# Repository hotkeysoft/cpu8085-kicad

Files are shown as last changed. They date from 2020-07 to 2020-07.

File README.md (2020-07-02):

# 8085 Computer
Rev A September 2018

Based on original 2001 design

Features
============
- 32KB ROM 
  - Address [0x0000-7FFF]
- 32KB RAM
  - Address [0x8000-FFFF]
- 82C54 PIT (Programmable Interval Timer) 
  - Port [0x40-0x43]
- UART 8250 or 16550 
  - Port [0x60-0x67]
  - Connected to FTDI Serial<->USB Adapter

Notes
============
- No voltage regulation on board, no protection of any kind
- I made a somewhat working BASIC interpreter from scratch that runs on this hardware: [pfe_8085basic](https://github.com/hotkeysoft/pfe_8085basic)

Changes from original design
============
- Changed crystal to 4MHz (CPU Freq = 2MHz)
	- Original design ran at 1.8432MHz (CPU Freq = 921.6KHz)

- Replaced MAX232 chip with FTDI USB module

- Replaced 2 PLA (address latch) with one 74HCT573 (for A[0..7] only, not needed for A[8..15])

- Instead of MISC (0x80) port and additional logic for gating the sound, used /OUT1 of 8250 UART
	- /OUT2 remains unused
	- Needed to invert /OUT2 signal to gate 82C54 timer, and to invert the sound output
		- 2 inverters added to DTGLUE3 (see below)

- Removed IO Decoding chip, moved /UART and /PIT decoding to DTGLUE3
	- Removed IO Decoding for keyboard and LCD

- Glue logic PLA (DTGLUE3) improvements from original DTGLUE1 (see PLD/DTGLUE3.PDS)
	- Removed /IOR, /IOW, /MR, /MW - not needed with properly constructed /CS signals and CPU /WR /RD
		- Added IO Decoding (/CS signal for /UART and /PIT)
	- Removed ALE, no need for inverted signal since switching to 74HCT573
	- Replaced A15 A7 A6 A5 (redundant because A15 == A7 for IO) with A15 A14 A13
		- On 8085, for IO Ports, port address is on both A[0..7] AND A[8..15]
	- 3 inputs and 3 outputs remain on PLA, for future use	

Images
============
PCB Render                                       |  Real PCB
:-----------------------------------------------:|:--------------------------------------------:
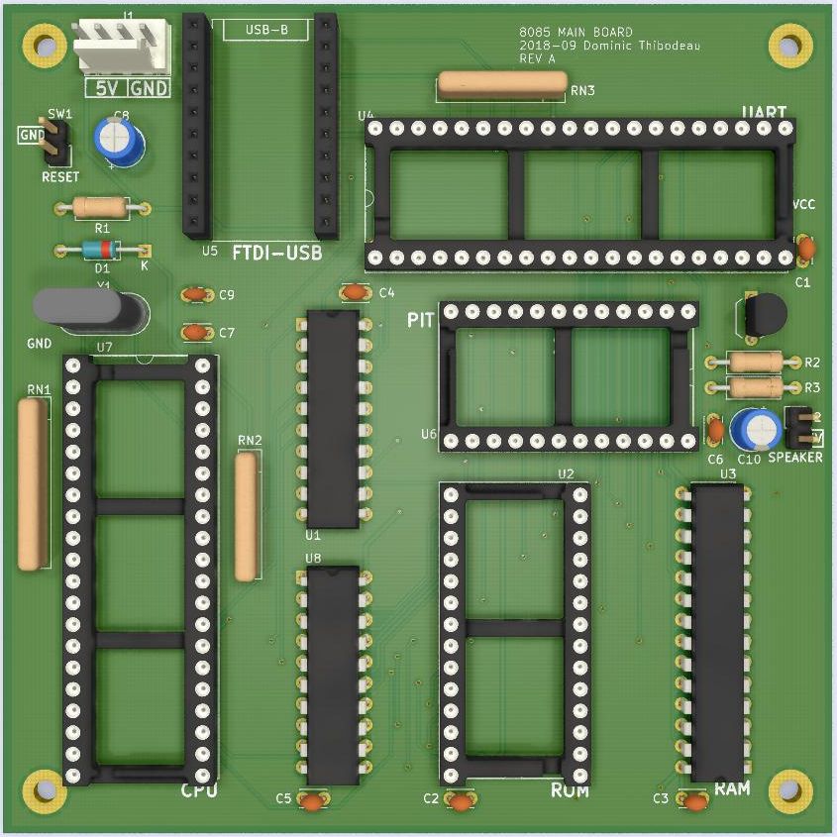
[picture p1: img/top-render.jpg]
PCB Render
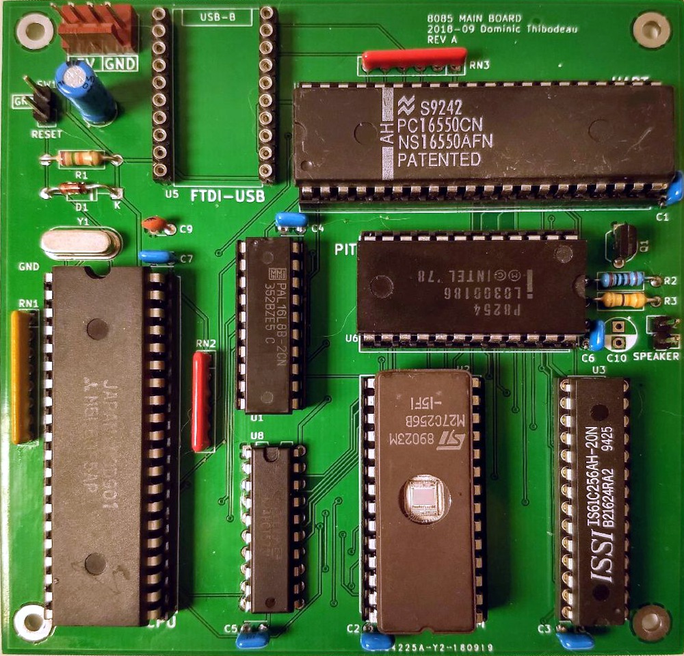
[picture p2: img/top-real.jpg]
Real PCB
 | 

### Schematics (pdf)
- [Complete schematics](./img/schema.pdf)

### PCB Images (svg)
- [Top](./img/pcb-front.svg)
- [Bottom](./img/pcb-back.svg)

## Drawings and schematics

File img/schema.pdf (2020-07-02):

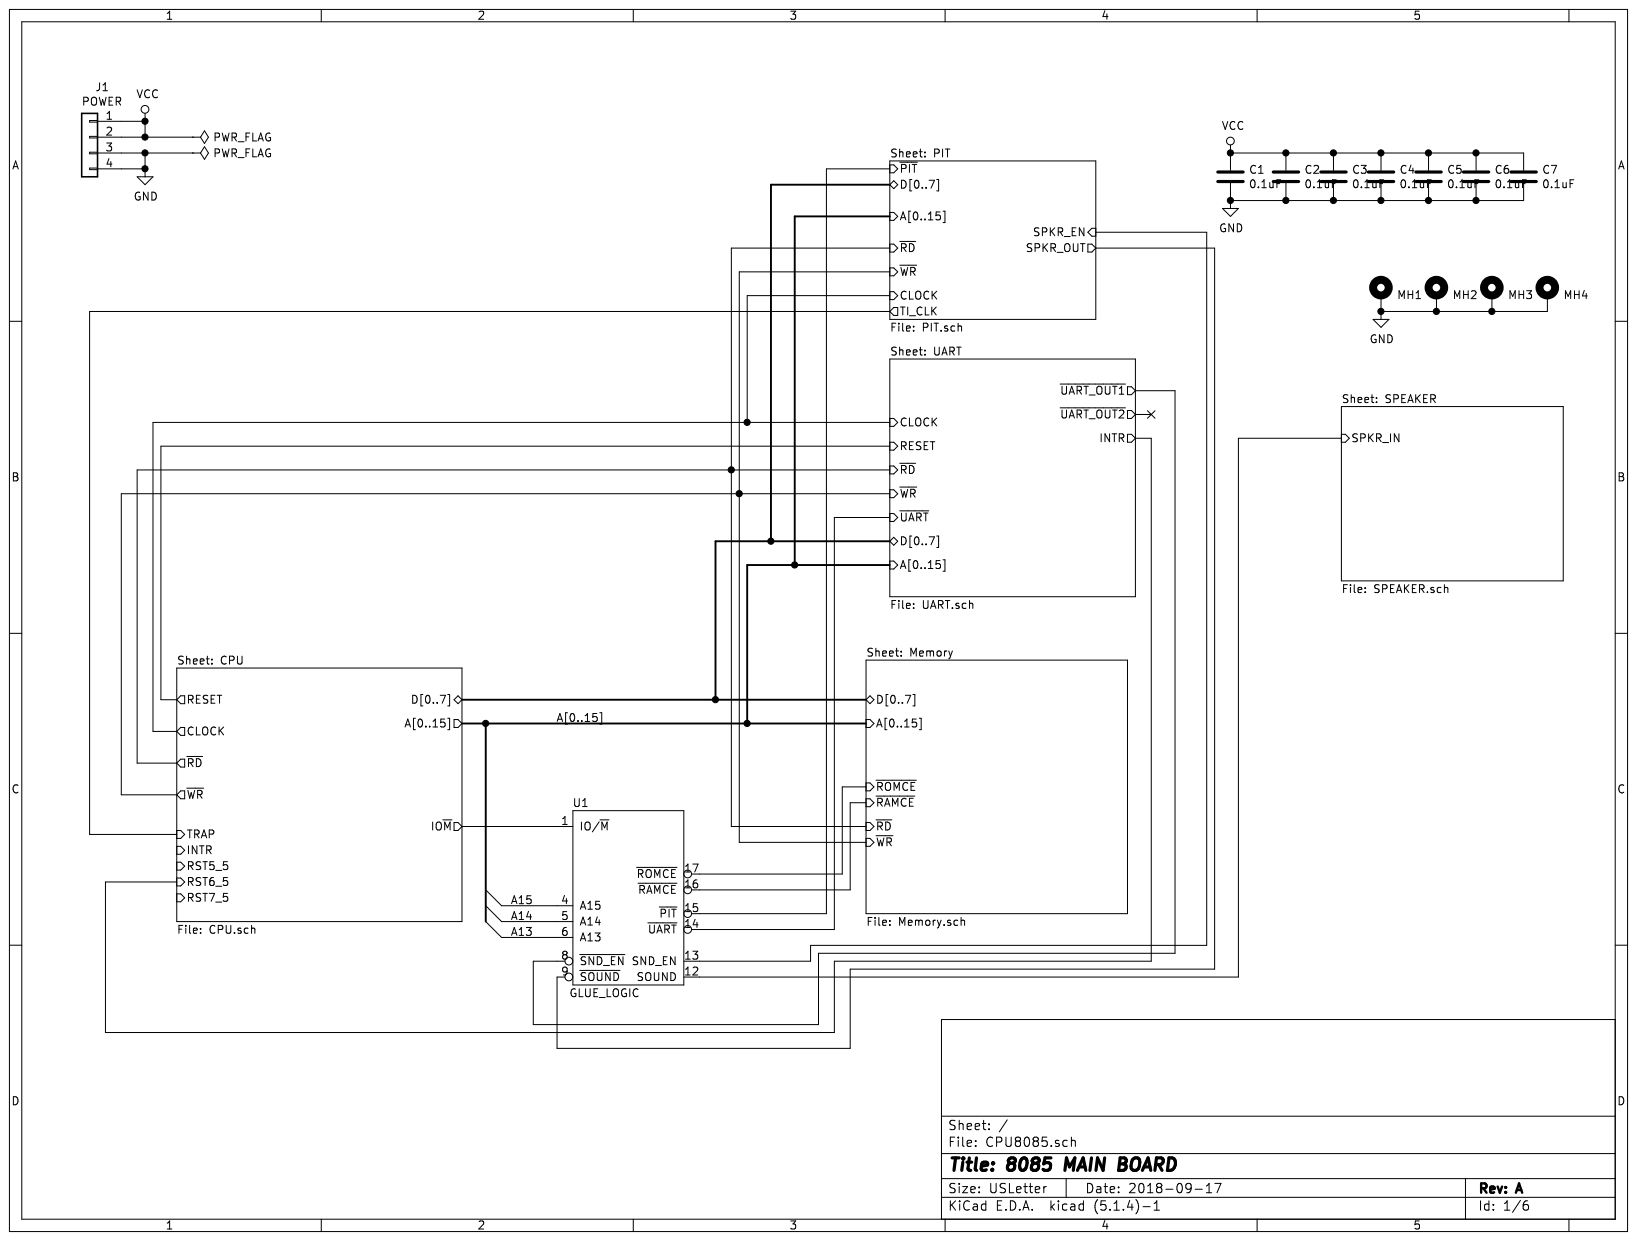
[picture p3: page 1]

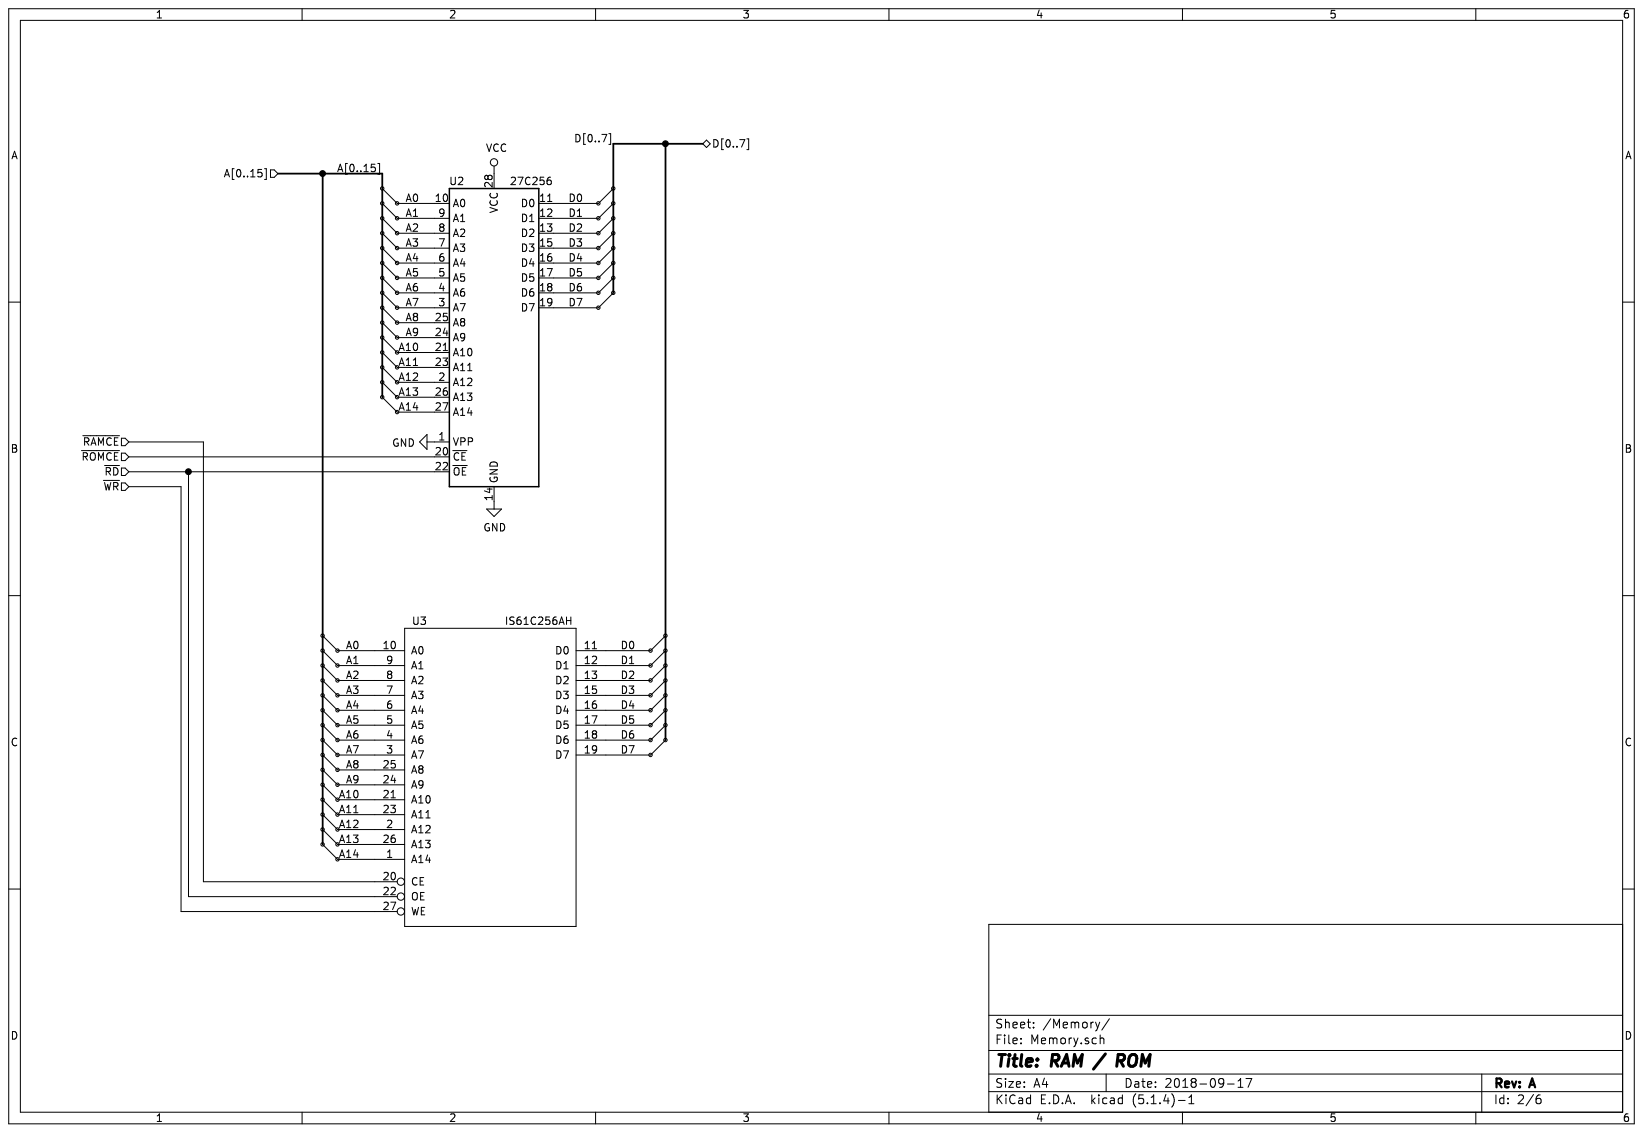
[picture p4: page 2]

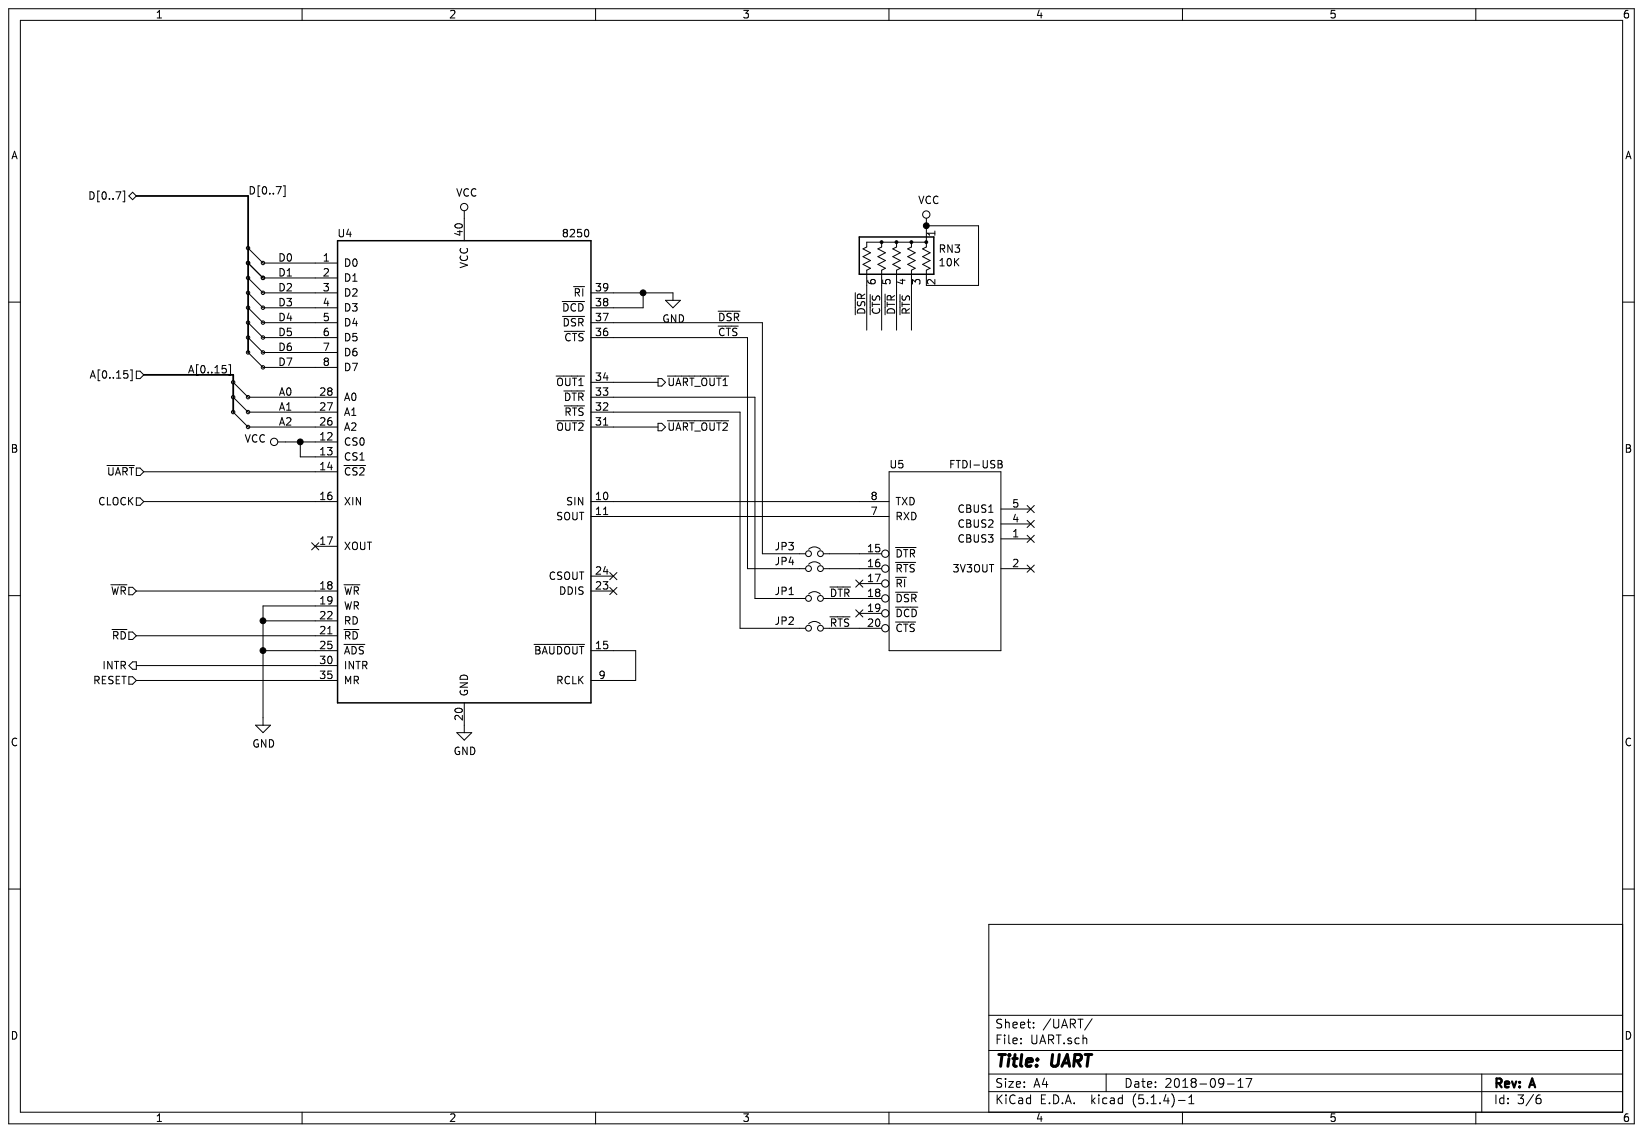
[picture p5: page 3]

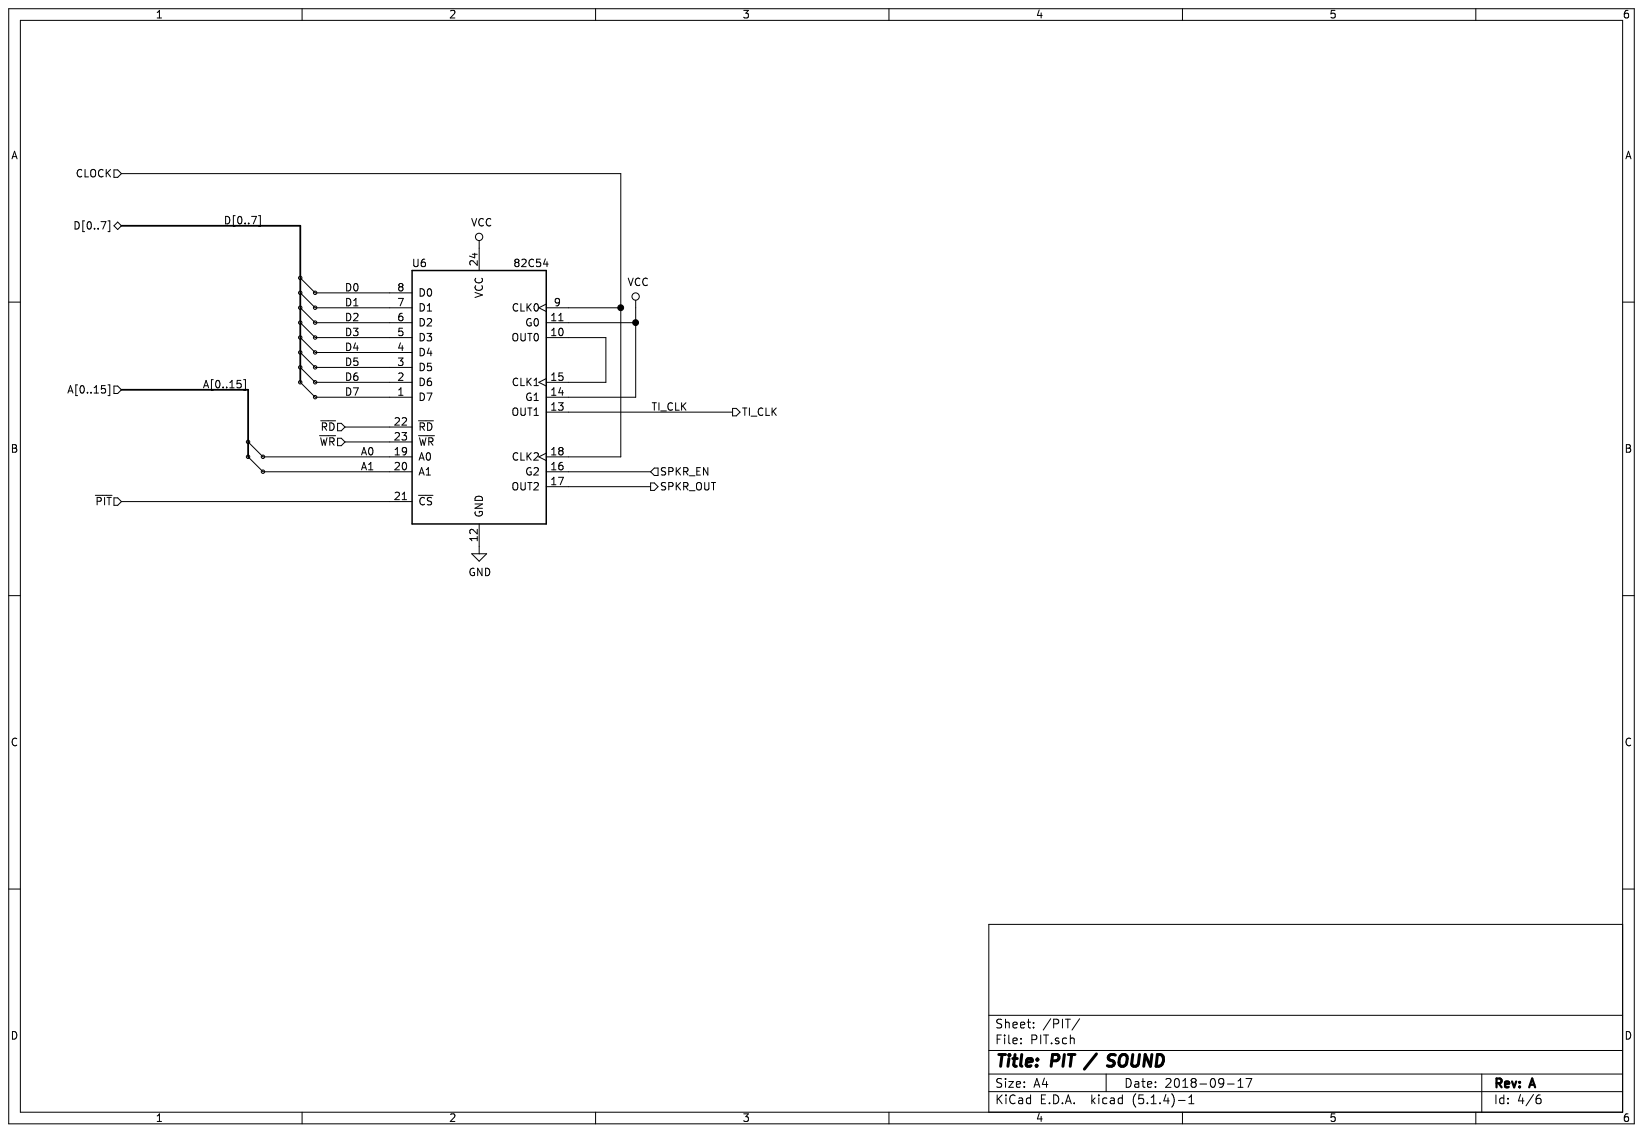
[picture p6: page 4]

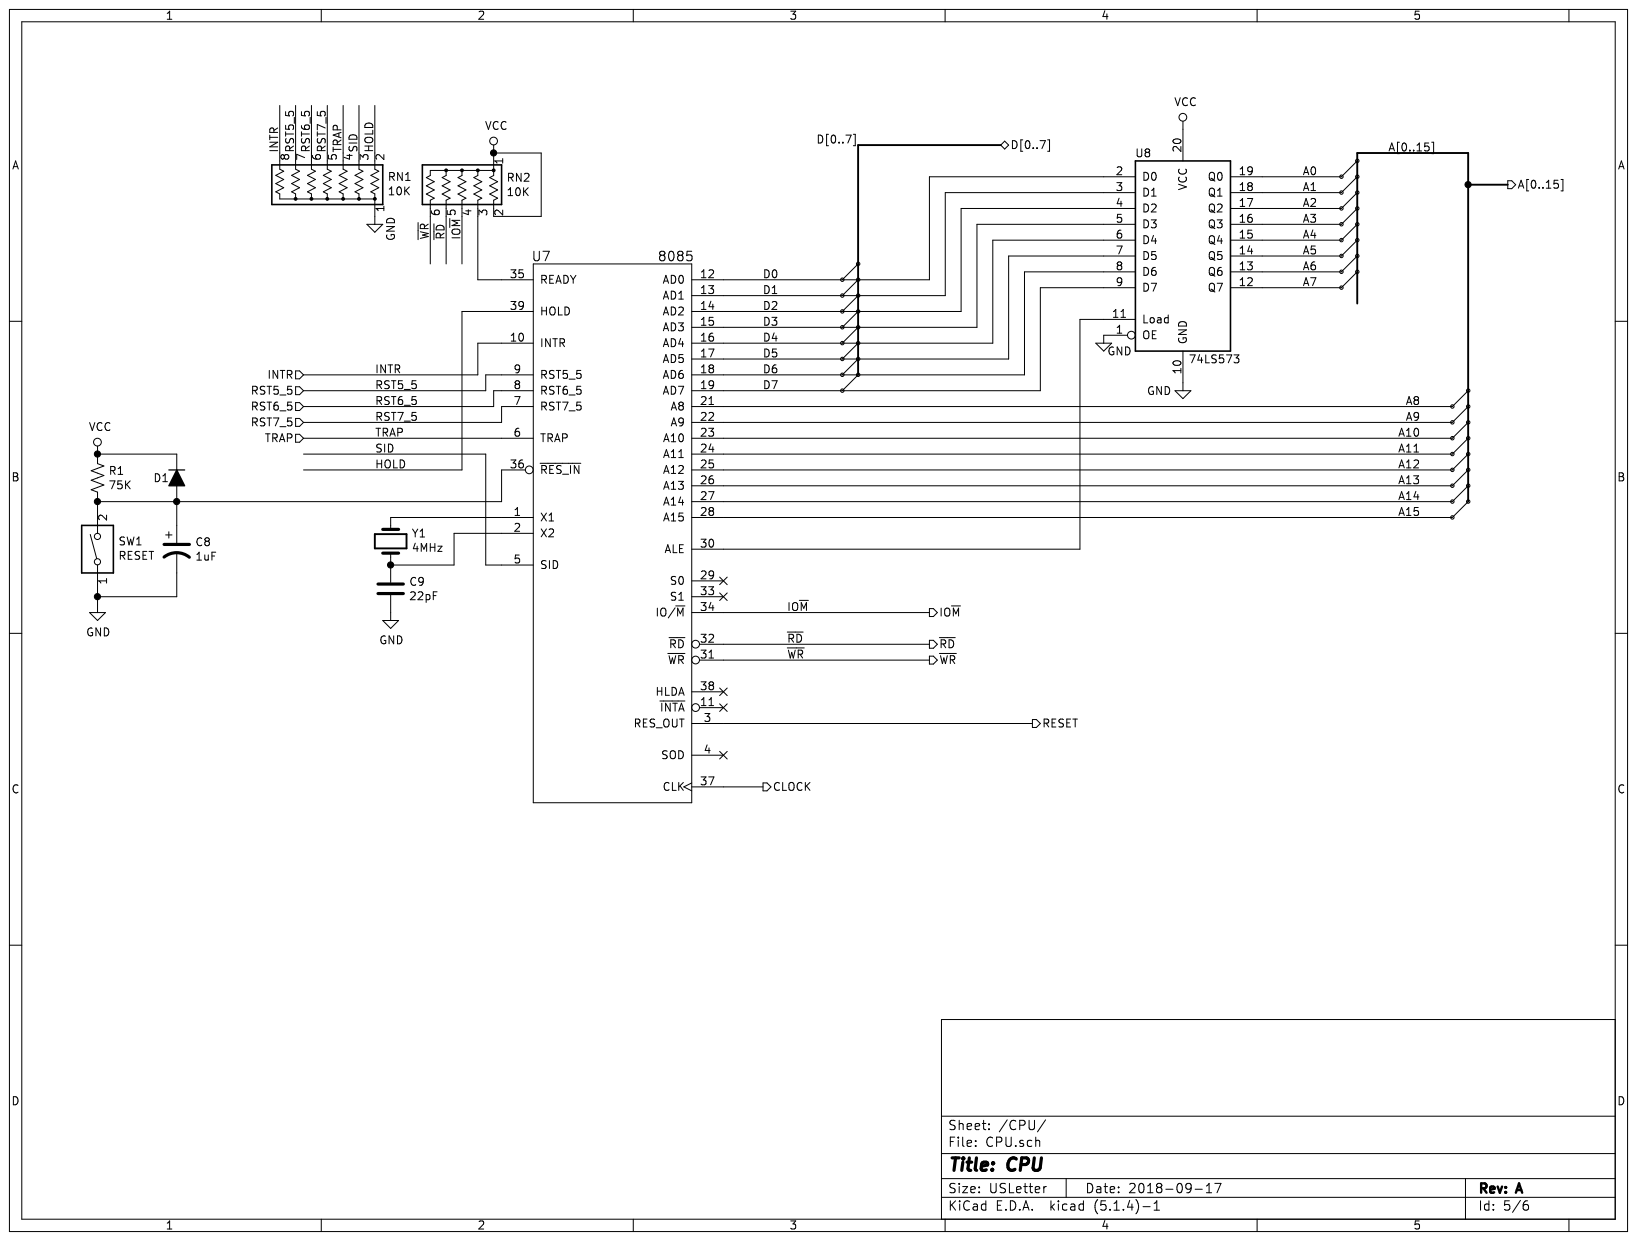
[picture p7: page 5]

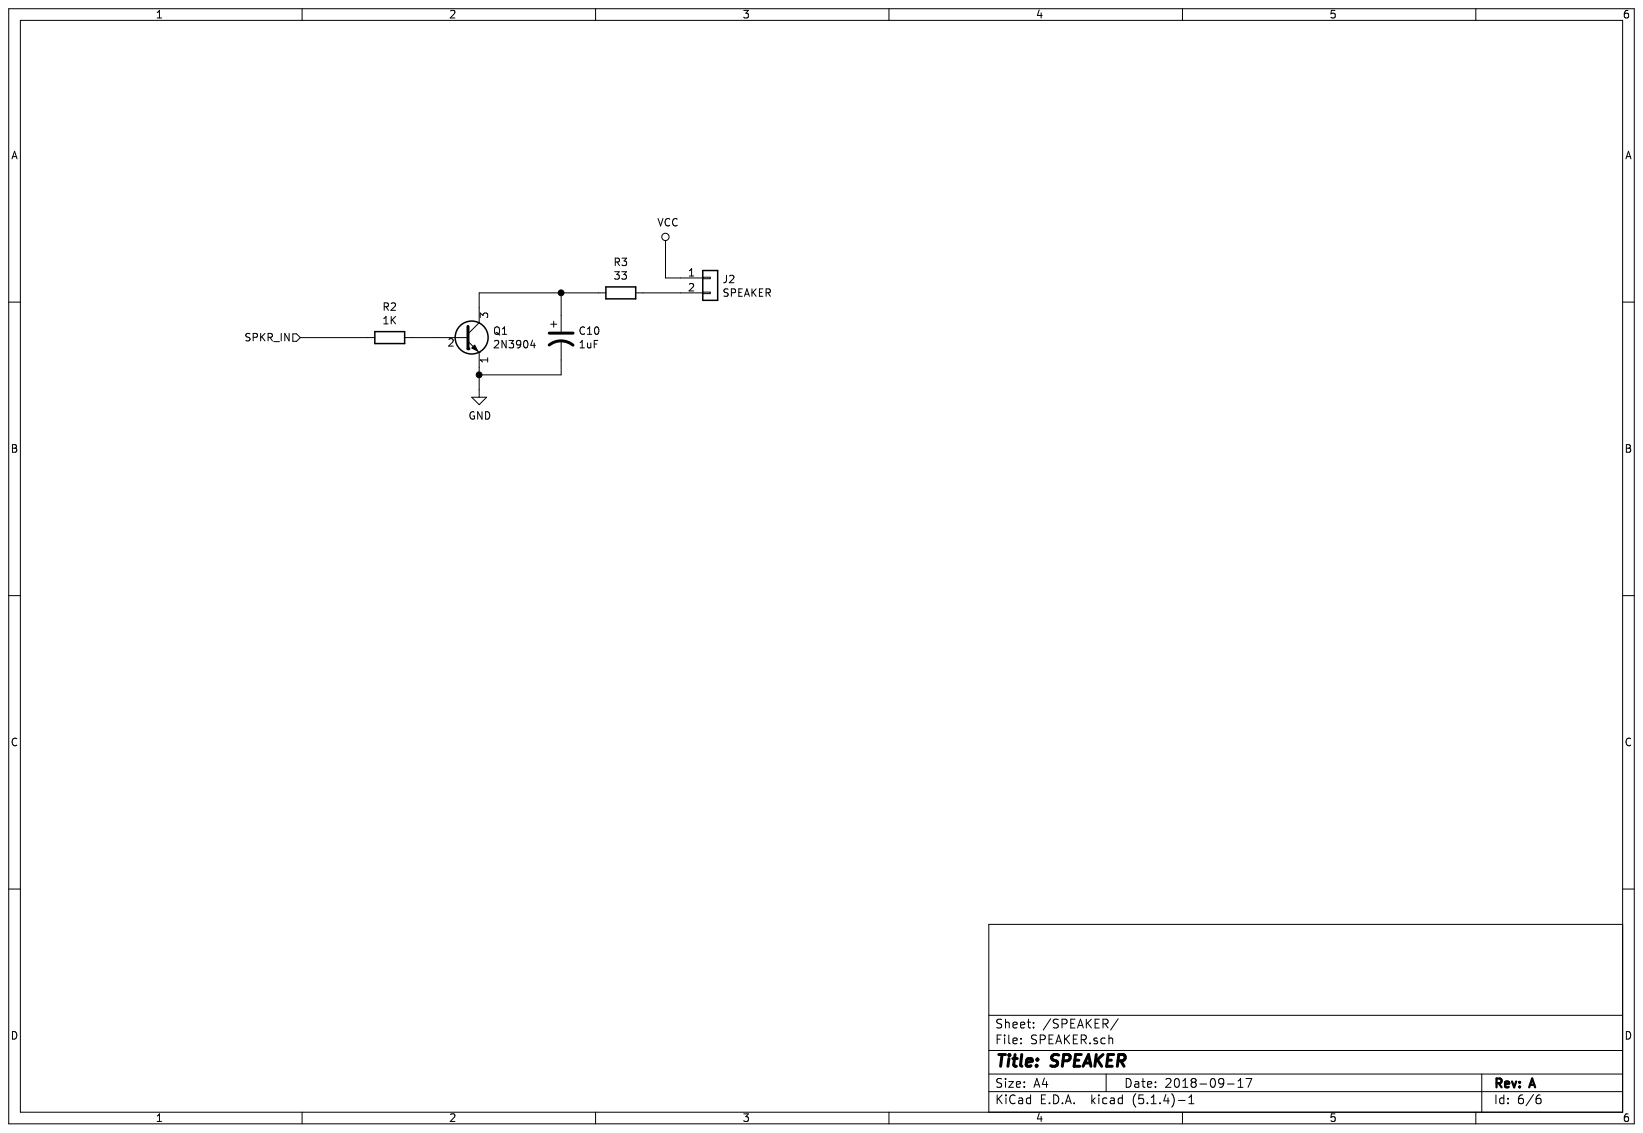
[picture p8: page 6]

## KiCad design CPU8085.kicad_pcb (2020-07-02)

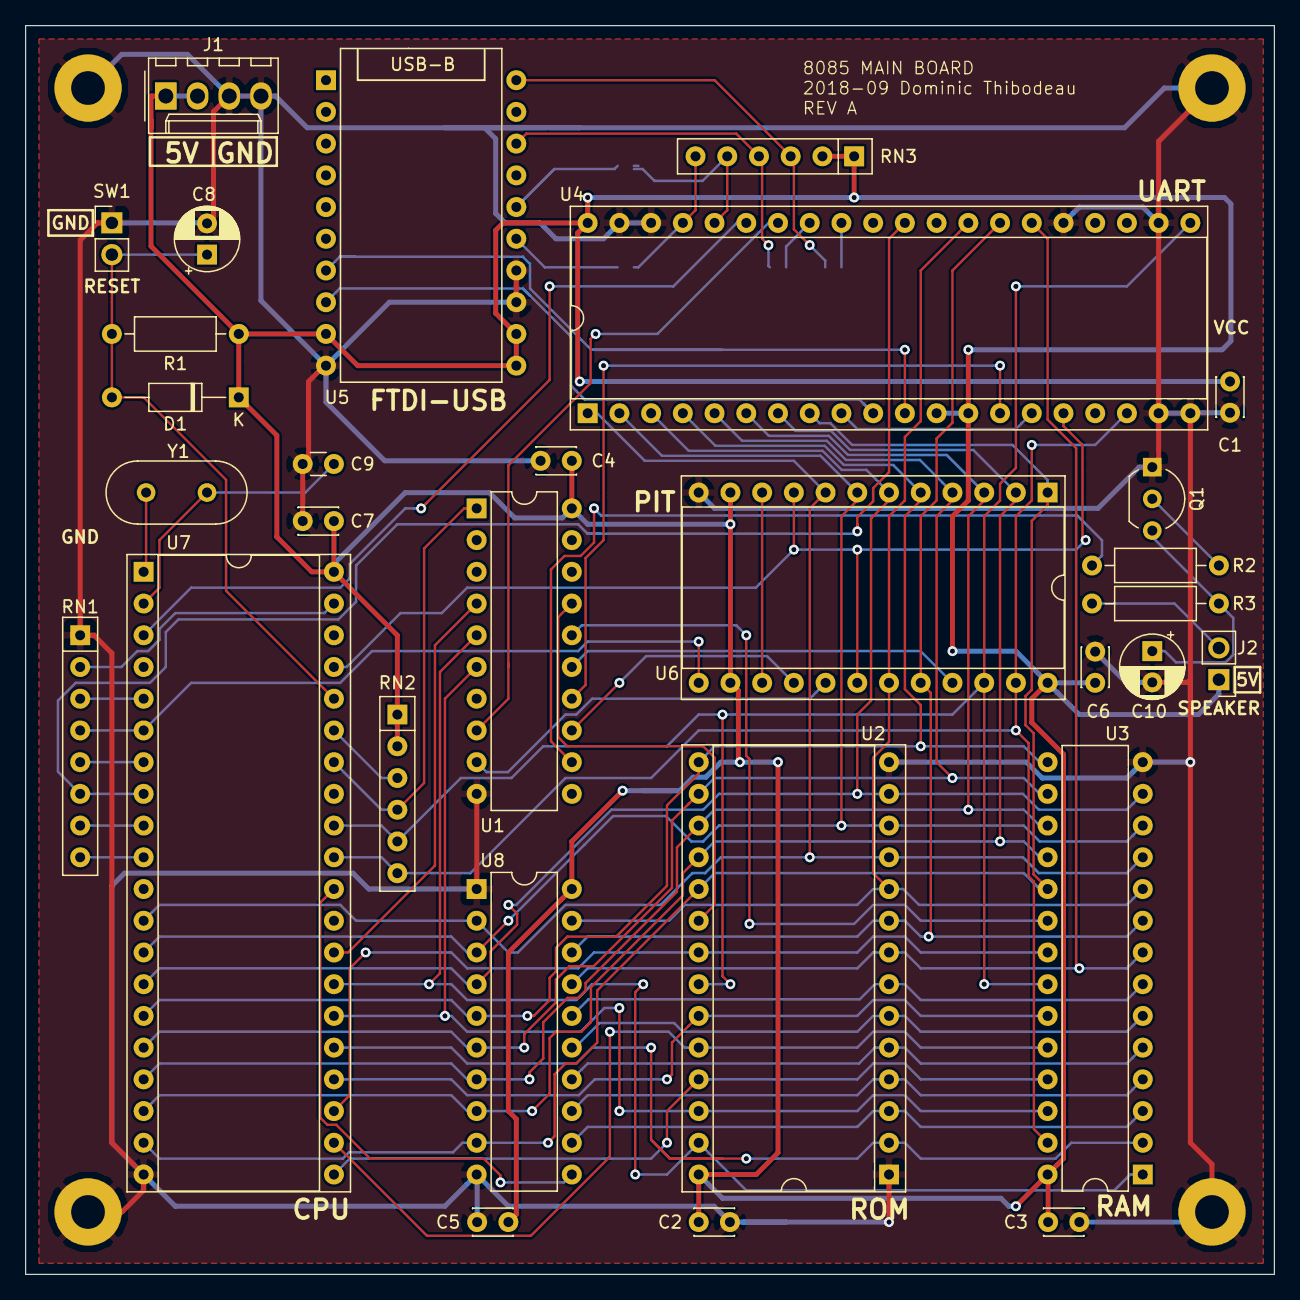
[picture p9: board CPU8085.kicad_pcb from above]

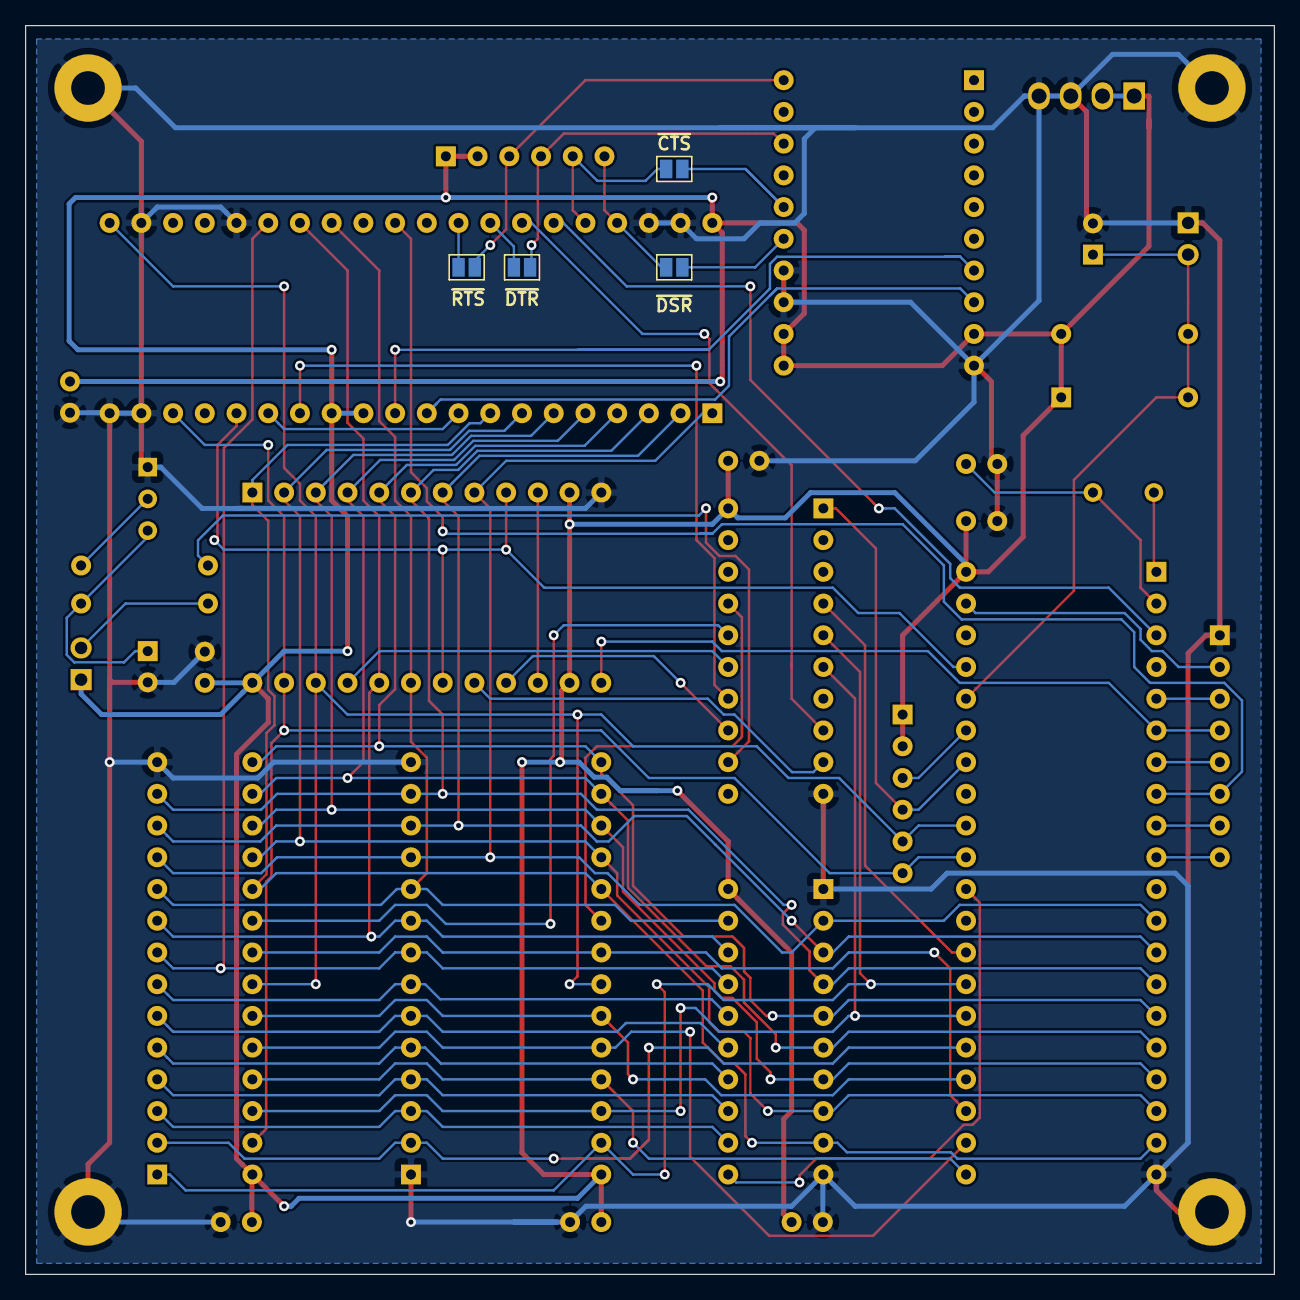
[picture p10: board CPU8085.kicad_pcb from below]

Board: 2 copper layers, 100.0 x 100.0 mm, 38 parts (4 on the bottom side), 66 nets.

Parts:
C1, C2, C3, C4, C5, C6, C7: 0.1uF; C_Disc_D3.0mm_W2.0mm_P2.50mm
C8, C10: 1uF; CP_Radial_D5.0mm_P2.50mm
C9: 22pF; C_Disc_D3.0mm_W1.6mm_P2.50mm
D1: 1N4004; D_DO-35_SOD27_P10.16mm_Horizontal
J1: POWER; Molex_KK-254_AE-6410-04A_1x04_P2.54mm_Vertical
J2: SPEAKER; PinHeader_1x02_P2.54mm_Vertical
JP1: ~DTR; SolderJumper-2_P1.3mm_Open_Pad1.0x1.5mm
JP2: ~RTS; SolderJumper-2_P1.3mm_Open_Pad1.0x1.5mm
JP3: ~DSR; SolderJumper-2_P1.3mm_Open_Pad1.0x1.5mm
JP4: ~CTS; SolderJumper-2_P1.3mm_Open_Pad1.0x1.5mm
MH1, MH2, MH3, MH4: MountingHole_Pad; MountingHole_2.7mm_M2.5_Pad
Q1: 2N3904; TO-92_Inline_Wide
R1: 75K; R_Axial_DIN0207_L6.3mm_D2.5mm_P10.16mm_Horizontal
R2: 1K; R_Axial_DIN0207_L6.3mm_D2.5mm_P10.16mm_Horizontal
R3: 33; R_Axial_DIN0207_L6.3mm_D2.5mm_P10.16mm_Horizontal
RN1: 10K; R_Array_SIP8
RN2, RN3: 10K; R_Array_SIP6
SW1: RESET; PinHeader_1x02_P2.54mm_Vertical
U1: GLUE_LOGIC; DIP-20_W7.62mm
U2: 27C256; DIP-28_W15.24mm_Socket
U3: IS61C256AH; DIP-28_W7.62mm
U4: 8250; DIP-40_W15.24mm_Socket
U5: FTDI-USB; FTDI_USB
U6: 82C54; DIP-24_W15.24mm_Socket
U7: 8085; DIP-40_W15.24mm_Socket
U8: 74LS573; DIP-20_W7.62mm
Y1: 4MHz; Crystal_HC49-U_Vertical

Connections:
/A13: U1.6, U2.26, U3.26, U7.26
/A14: U1.5, U2.27, U3.1, U7.27
/A15: U1.4, U7.28
/CPU/A0: U2.10, U3.10, U4.28, U6.19, U8.19
/CPU/A1: U2.9, U3.9, U4.27, U6.20, U8.18
/CPU/A2: U2.8, U3.8, U4.26, U8.17
/CPU/A3: U2.7, U3.7, U8.16
/CPU/A4: U2.6, U3.6, U8.15
/CPU/A5: U2.5, U3.5, U8.14
/CPU/A6: U2.4, U3.4, U8.13
/CPU/A7: U2.3, U3.3, U8.12
/CPU/A8: U2.25, U3.25, U7.21
/CPU/A9: U2.24, U3.24, U7.22
/CPU/A10: U2.21, U3.21, U7.23
/CPU/A11: U2.23, U3.23, U7.24
/CPU/A12: U2.2, U3.2, U7.25
/CPU/CLOCK: U4.16, U6.9, U6.18, U7.37
/CPU/D0: U2.11, U3.11, U4.1, U6.8, U7.12, U8.2
/CPU/D1: U2.12, U3.12, U4.2, U6.7, U7.13, U8.3
/CPU/D2: U2.13, U3.13, U4.3, U6.6, U7.14, U8.4
/CPU/D3: U2.15, U3.15, U4.4, U6.5, U7.15, U8.5
/CPU/D4: U2.16, U3.16, U4.5, U6.4, U7.16, U8.6
/CPU/D5: U2.17, U3.17, U4.6, U6.3, U7.17, U8.7
/CPU/D6: U2.18, U3.18, U4.7, U6.2, U7.18, U8.8
/CPU/D7: U2.19, U3.19, U4.8, U6.1, U7.19, U8.9
/CPU/HOLD: RN1.2, U7.39
/CPU/INTR: RN1.8, U7.10
/CPU/IO~M: RN2.4, U1.1, U7.34
/CPU/RESET: U4.35, U7.3
/CPU/RST5_5: RN1.7, U7.9
/CPU/RST7_5: RN1.5, U7.7
/CPU/SID: RN1.3, U7.5
/CPU/~RD: RN2.5, U2.22, U3.22, U4.21, U6.22, U7.32
/CPU/~WR: RN2.6, U3.27, U4.18, U6.23, U7.31
/Memory/~RAMCE: U1.16, U3.20
/Memory/~ROMCE: U1.17, U2.20
/PIT/SPKR_EN: U1.13, U6.16
/PIT/SPKR_OUT: U1.9, U6.17
/PIT/TI_CLK: RN1.4, U6.13, U7.6
/PIT/~PIT: U1.15, U6.21
/SPEAKER/SPKR_IN: R2.2, U1.12
/UART/INTR: RN1.6, U4.30, U7.8
/UART/~CTS: JP4.1, RN3.5, U4.36
/UART/~DSR: JP3.1, RN3.6, U4.37
/UART/~DTR: JP1.2, RN3.4, U5.18
/UART/~RTS: JP2.2, RN3.3, U5.20
/UART/~UART: U1.14, U4.14
/UART/~UART_OUT1: U1.8, U4.34
GND: C1.2, C2.2, C3.2, C4.2, C5.2, C6.2, C7.2, C8.2, C9.2, C10.2, J1.3, J1.4, MH1.1, MH2.1, MH3.1, MH4.1, Q1.1, RN1.1, SW1.1, U1.10, U2.1, U2.14, U3.14, U4.19, U4.20, U4.22, U4.25, U4.38, U4.39, U5.10, U5.13, U5.14, U6.12, U7.20, U8.1, U8.10
unnamed: C8.1, D1.2, R1.2, SW1.2, U7.36
unnamed: C9.1, U7.2, Y1.1
unnamed: C10.1, Q1.3, R3.2
unnamed: J2.2, R3.1
unnamed: JP1.1, U4.33
unnamed: JP2.1, U4.32
unnamed: JP3.2, U5.15
unnamed: JP4.2, U5.16
unnamed: Q1.2, R2.1
unnamed: RN2.3, U7.35
unnamed: U4.10, U5.8
unnamed: U4.11, U5.7
unnamed: U4.9, U4.15
unnamed: U6.10, U6.15
unnamed: U7.1, Y1.2
unnamed: U7.30, U8.11
VCC: C1.1, C2.1, C3.1, C4.1, C5.1, C6.1, C7.1, D1.1, J1.1, J1.2, J2.1, R1.1, RN2.1, RN2.2, RN3.1, RN3.2, U1.20, U2.28, U3.28, U4.12, U4.13, U4.40, U5.9, U5.11, U5.12, U6.11, U6.14, U6.24, U7.40, U8.20

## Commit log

2018-09-19 Moved to RevA
    [CPU.sch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]
2018-10-16 Added bom
2020-07-02 Fixed footprint for FTDI adapter
    [CPU8085.kicad_pcb]
